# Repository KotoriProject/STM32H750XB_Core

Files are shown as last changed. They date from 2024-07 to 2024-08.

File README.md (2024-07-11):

# STM32 H750XBH6 核心板设计规划
## 设计理念
从STM32的F0、F1系列一路至今，到目前最为复杂的H750IBK6开发板、核心板的设计，逐渐认识到了单片机系统的设计思路。

在使用低性能单片机的情况下，通常最小系统的PCB layout只需要普通的两层即可。因此，在这种情况下，应当尽量采用**一体化设计**，既可以节省PCB成本，又无需考虑多个PCB之间的耦合设计。

但如果使用的是像H7这一类的**高性能芯片**，并且，这些芯片因为其封装、外部扩展ram等等，会导致最小系统的复杂度急剧提升，PCB layout通常都需要**4层甚至以上的设计**，此时，如果还像低性能单片机一样一体化设计，将核心系统和外围系统设计到一个PCB上，不仅会无故增加成本，并且每一个不同的项目需求的外围电路不尽相同，若更改外围电路则需要连同核心系统一起更改，将会**花费大量时间在重复设计核心系统上**。

因此，采用核心板+底板的设计方式应运而生。通过将核心系统单独设计成一块固定的PCB，并通过引出**具有通用性的接口**，可以使得核心系统**随意**搭配不同的底板（外围电路）。
## 设计目标
1. 通过设计该核心板和对应配套的底板，在实践中学习到相应的知识。
2. 设计出一款可以使用核心芯片所具有的广泛的外设接口、并核心自身又有搭载必要的**内存拓展空间**。
3. 利用设计出的核心板和底板，实现各种个人构想的项目。

## 硬件设计
### Power
参考ST官方给出的H7电源设计，STM32H750XBH6共有以下供电域：

1. dw
2. 123
3. 321
4. 313421414
5. 
123321414
### External Memory
### GPIO AFIO
### Debug Port
### Physical Port

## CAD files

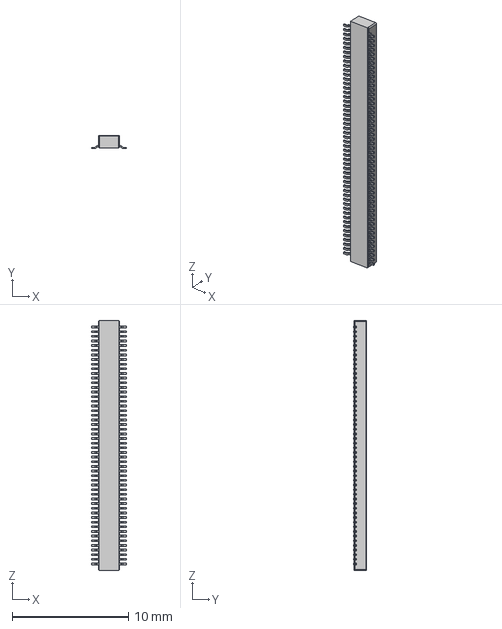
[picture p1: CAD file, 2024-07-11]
PCB/kicad_project/HRS/DF40C-100DP-0.4V_51_.step
2.97 x 1.14 x 21.5 mm

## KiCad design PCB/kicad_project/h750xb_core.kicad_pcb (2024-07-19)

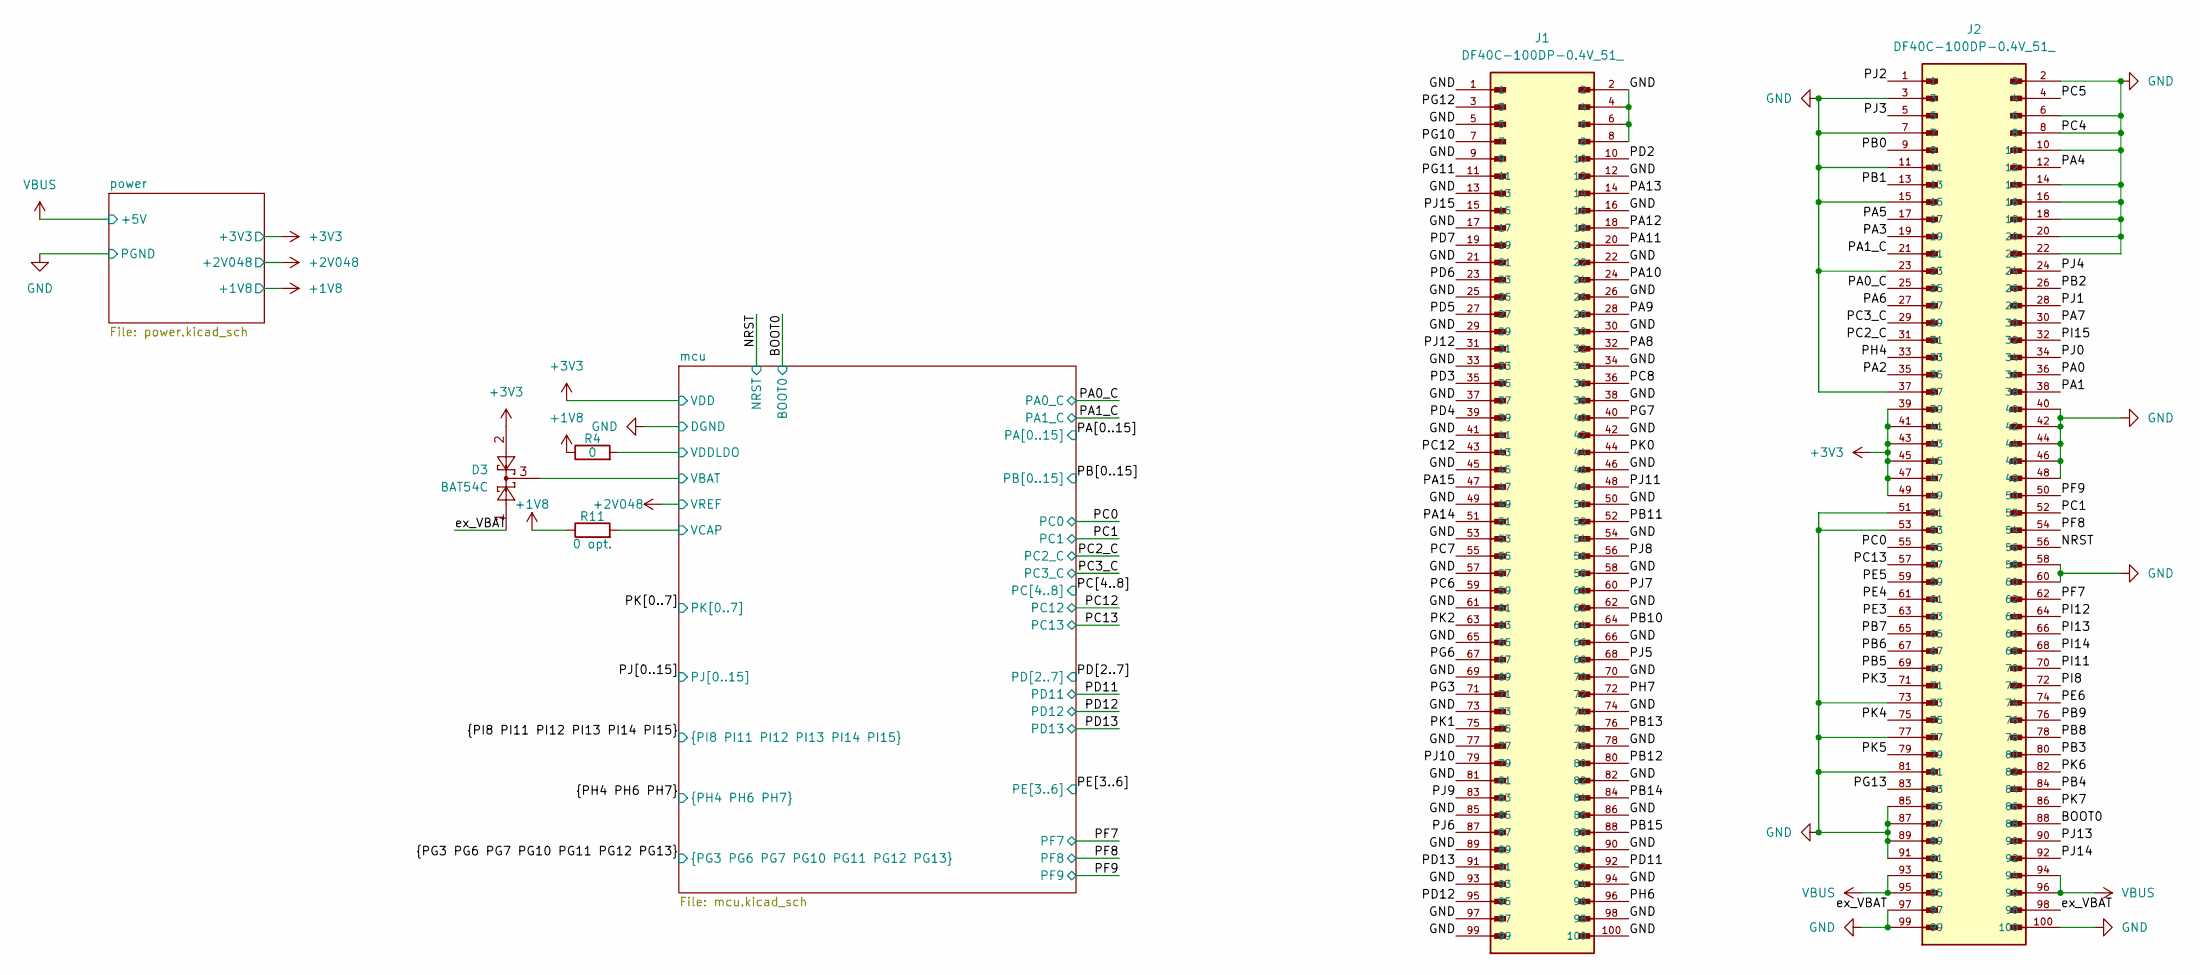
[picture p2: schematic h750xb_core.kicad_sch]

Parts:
D3: BAT54C; SOT-23
J1, J2: DF40C-100DP-0.4V_51_; HIROSE_DF40C-100DP-0.4V_51_; PARTREV 8
R4: 0; R_0603_1608Metric
R11: 0 opt.; R_0603_1608Metric

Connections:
+1V8: R4.1, R11.1; also elsewhere on the board
+3V3: D3.2, J2.39, J2.41, J2.43, J2.45, J2.47, J2.49; also elsewhere on the board
/BOOT0: J2.88; also elsewhere on the board
/NRST: J2.56; also elsewhere on the board
/PA0: J2.36; also elsewhere on the board
/PA0_C: J2.25; also elsewhere on the board
/PA1: J2.38; also elsewhere on the board
/PA1_C: J2.21; also elsewhere on the board
/PA2: J2.35; also elsewhere on the board
/PA3: J2.19; also elsewhere on the board
/PA4: J2.12; also elsewhere on the board
/PA5: J2.17; also elsewhere on the board
/PA6: J2.27; also elsewhere on the board
/PA7: J2.30; also elsewhere on the board
/PA8: J1.32; also elsewhere on the board
/PA9: J1.28; also elsewhere on the board
/PA10: J1.24; also elsewhere on the board
/PA11: J1.20; also elsewhere on the board
/PA12: J1.18; also elsewhere on the board
/PA13: J1.14; also elsewhere on the board
/PA14: J1.51; also elsewhere on the board
/PA15: J1.47; also elsewhere on the board
/PB0: J2.9; also elsewhere on the board
/PB1: J2.13; also elsewhere on the board
/PB2: J2.26; also elsewhere on the board
/PB3: J2.80; also elsewhere on the board
/PB4: J2.84; also elsewhere on the board
/PB5: J2.69; also elsewhere on the board
/PB6: J2.67; also elsewhere on the board
/PB7: J2.65; also elsewhere on the board
/PB8: J2.78; also elsewhere on the board
/PB9: J2.76; also elsewhere on the board
/PB10: J1.64; also elsewhere on the board
/PB11: J1.52; also elsewhere on the board
/PB12: J1.80; also elsewhere on the board
/PB13: J1.76; also elsewhere on the board
/PB14: J1.84; also elsewhere on the board
/PB15: J1.88; also elsewhere on the board
/PC0: J2.55; also elsewhere on the board
/PC1: J2.52; also elsewhere on the board
/PC2_C: J2.31; also elsewhere on the board
/PC3_C: J2.29; also elsewhere on the board
/PC5: J2.4; also elsewhere on the board
/PC6: J1.59; also elsewhere on the board
/PC7: J1.55; also elsewhere on the board
/PC8: J1.36; also elsewhere on the board
/PC12: J1.43; also elsewhere on the board
/PC13: J2.57; also elsewhere on the board
/PD2: J1.10; also elsewhere on the board
/PD3: J1.35; also elsewhere on the board
/PD4: J1.39; also elsewhere on the board
/PD5: J1.27; also elsewhere on the board
/PD6: J1.23; also elsewhere on the board
/PD7: J1.19; also elsewhere on the board
/PD11: J1.92; also elsewhere on the board
/PD12: J1.95; also elsewhere on the board
/PD13: J1.91; also elsewhere on the board
/PE3: J2.63; also elsewhere on the board
/PE4: J2.61; also elsewhere on the board
/PE5: J2.59; also elsewhere on the board
/PE6: J2.74; also elsewhere on the board
/PF7: J2.62; also elsewhere on the board
/PF8: J2.54; also elsewhere on the board
/PF9: J2.50; also elsewhere on the board
/PG3: J1.71; also elsewhere on the board
/PG6: J1.67; also elsewhere on the board
/PG7: J1.40; also elsewhere on the board
/PG10: J1.7; also elsewhere on the board
/PG11: J1.11; also elsewhere on the board
/PG12: J1.3; also elsewhere on the board
/PG13: J2.83; also elsewhere on the board
/PH4: J2.33; also elsewhere on the board
/PH6: J1.96; also elsewhere on the board
/PH7: J1.72; also elsewhere on the board
/PI8: J2.72; also elsewhere on the board
/PI11: J2.70; also elsewhere on the board
/PI12: J2.64; also elsewhere on the board
/PI13: J2.66; also elsewhere on the board
/PI14: J2.68; also elsewhere on the board
/PI15: J2.32; also elsewhere on the board
/PJ0: J2.34; also elsewhere on the board
/PJ1: J2.28; also elsewhere on the board
/PJ2: J2.1; also elsewhere on the board
/PJ3: J2.5; also elsewhere on the board
/PJ4: J2.24; also elsewhere on the board
/PJ5: J1.68; also elsewhere on the board
/PJ6: J1.87; also elsewhere on the board
/PJ7: J1.60; also elsewhere on the board
/PJ8: J1.56; also elsewhere on the board
/PJ9: J1.83; also elsewhere on the board
/PJ10: J1.79; also elsewhere on the board
/PJ11: J1.48; also elsewhere on the board
/PJ12: J1.31; also elsewhere on the board
/PJ13: J2.90; also elsewhere on the board
/PJ14: J2.92; also elsewhere on the board
/PJ15: J1.15; also elsewhere on the board
/PK0: J1.44; also elsewhere on the board
/PK1: J1.75; also elsewhere on the board
/PK2: J1.63; also elsewhere on the board
/PK3: J2.71; also elsewhere on the board
/PK4: J2.75; also elsewhere on the board
/PK5: J2.79; also elsewhere on the board
/PK6: J2.82; also elsewhere on the board
/PK7: J2.86; also elsewhere on the board
/mcu/VBAT: D3.3; also elsewhere on the board
/mcu/VCAP: R11.2; also elsewhere on the board
/mcu/VDDLDO: R4.2; also elsewhere on the board
GND: D3.1, J1.1, J1.2, J1.4, J1.5, J1.6, J1.8, J1.9, J1.12, J1.13, J1.16, J1.17, J1.21, J1.22, J1.25, J1.26, J1.29, J1.30, J1.33, J1.34, J1.37, J1.38, J1.41, J1.42, J1.45, J1.46, J1.49, J1.50, J1.53, J1.54, J1.57, J1.58, J1.61, J1.62, J1.65, J1.66, J1.69, J1.70, J1.73, J1.74, J1.77, J1.78, J1.81, J1.82, J1.85, J1.86, J1.89, J1.90, J1.93, J1.94, J1.97, J1.98, J1.99, J1.100, J2.2, J2.3, J2.6, J2.7, J2.8, J2.10, J2.11, J2.14, J2.15, J2.16, J2.18, J2.20, J2.22, J2.23, J2.37, J2.40, J2.42, J2.44, J2.46, J2.48, J2.51, J2.53, J2.58, J2.60, J2.73, J2.77, J2.81, J2.85, J2.87, J2.89, J2.91, J2.97, J2.98, J2.99, J2.100; also elsewhere on the board
VBUS: J2.93, J2.94, J2.95, J2.96; also elsewhere on the board

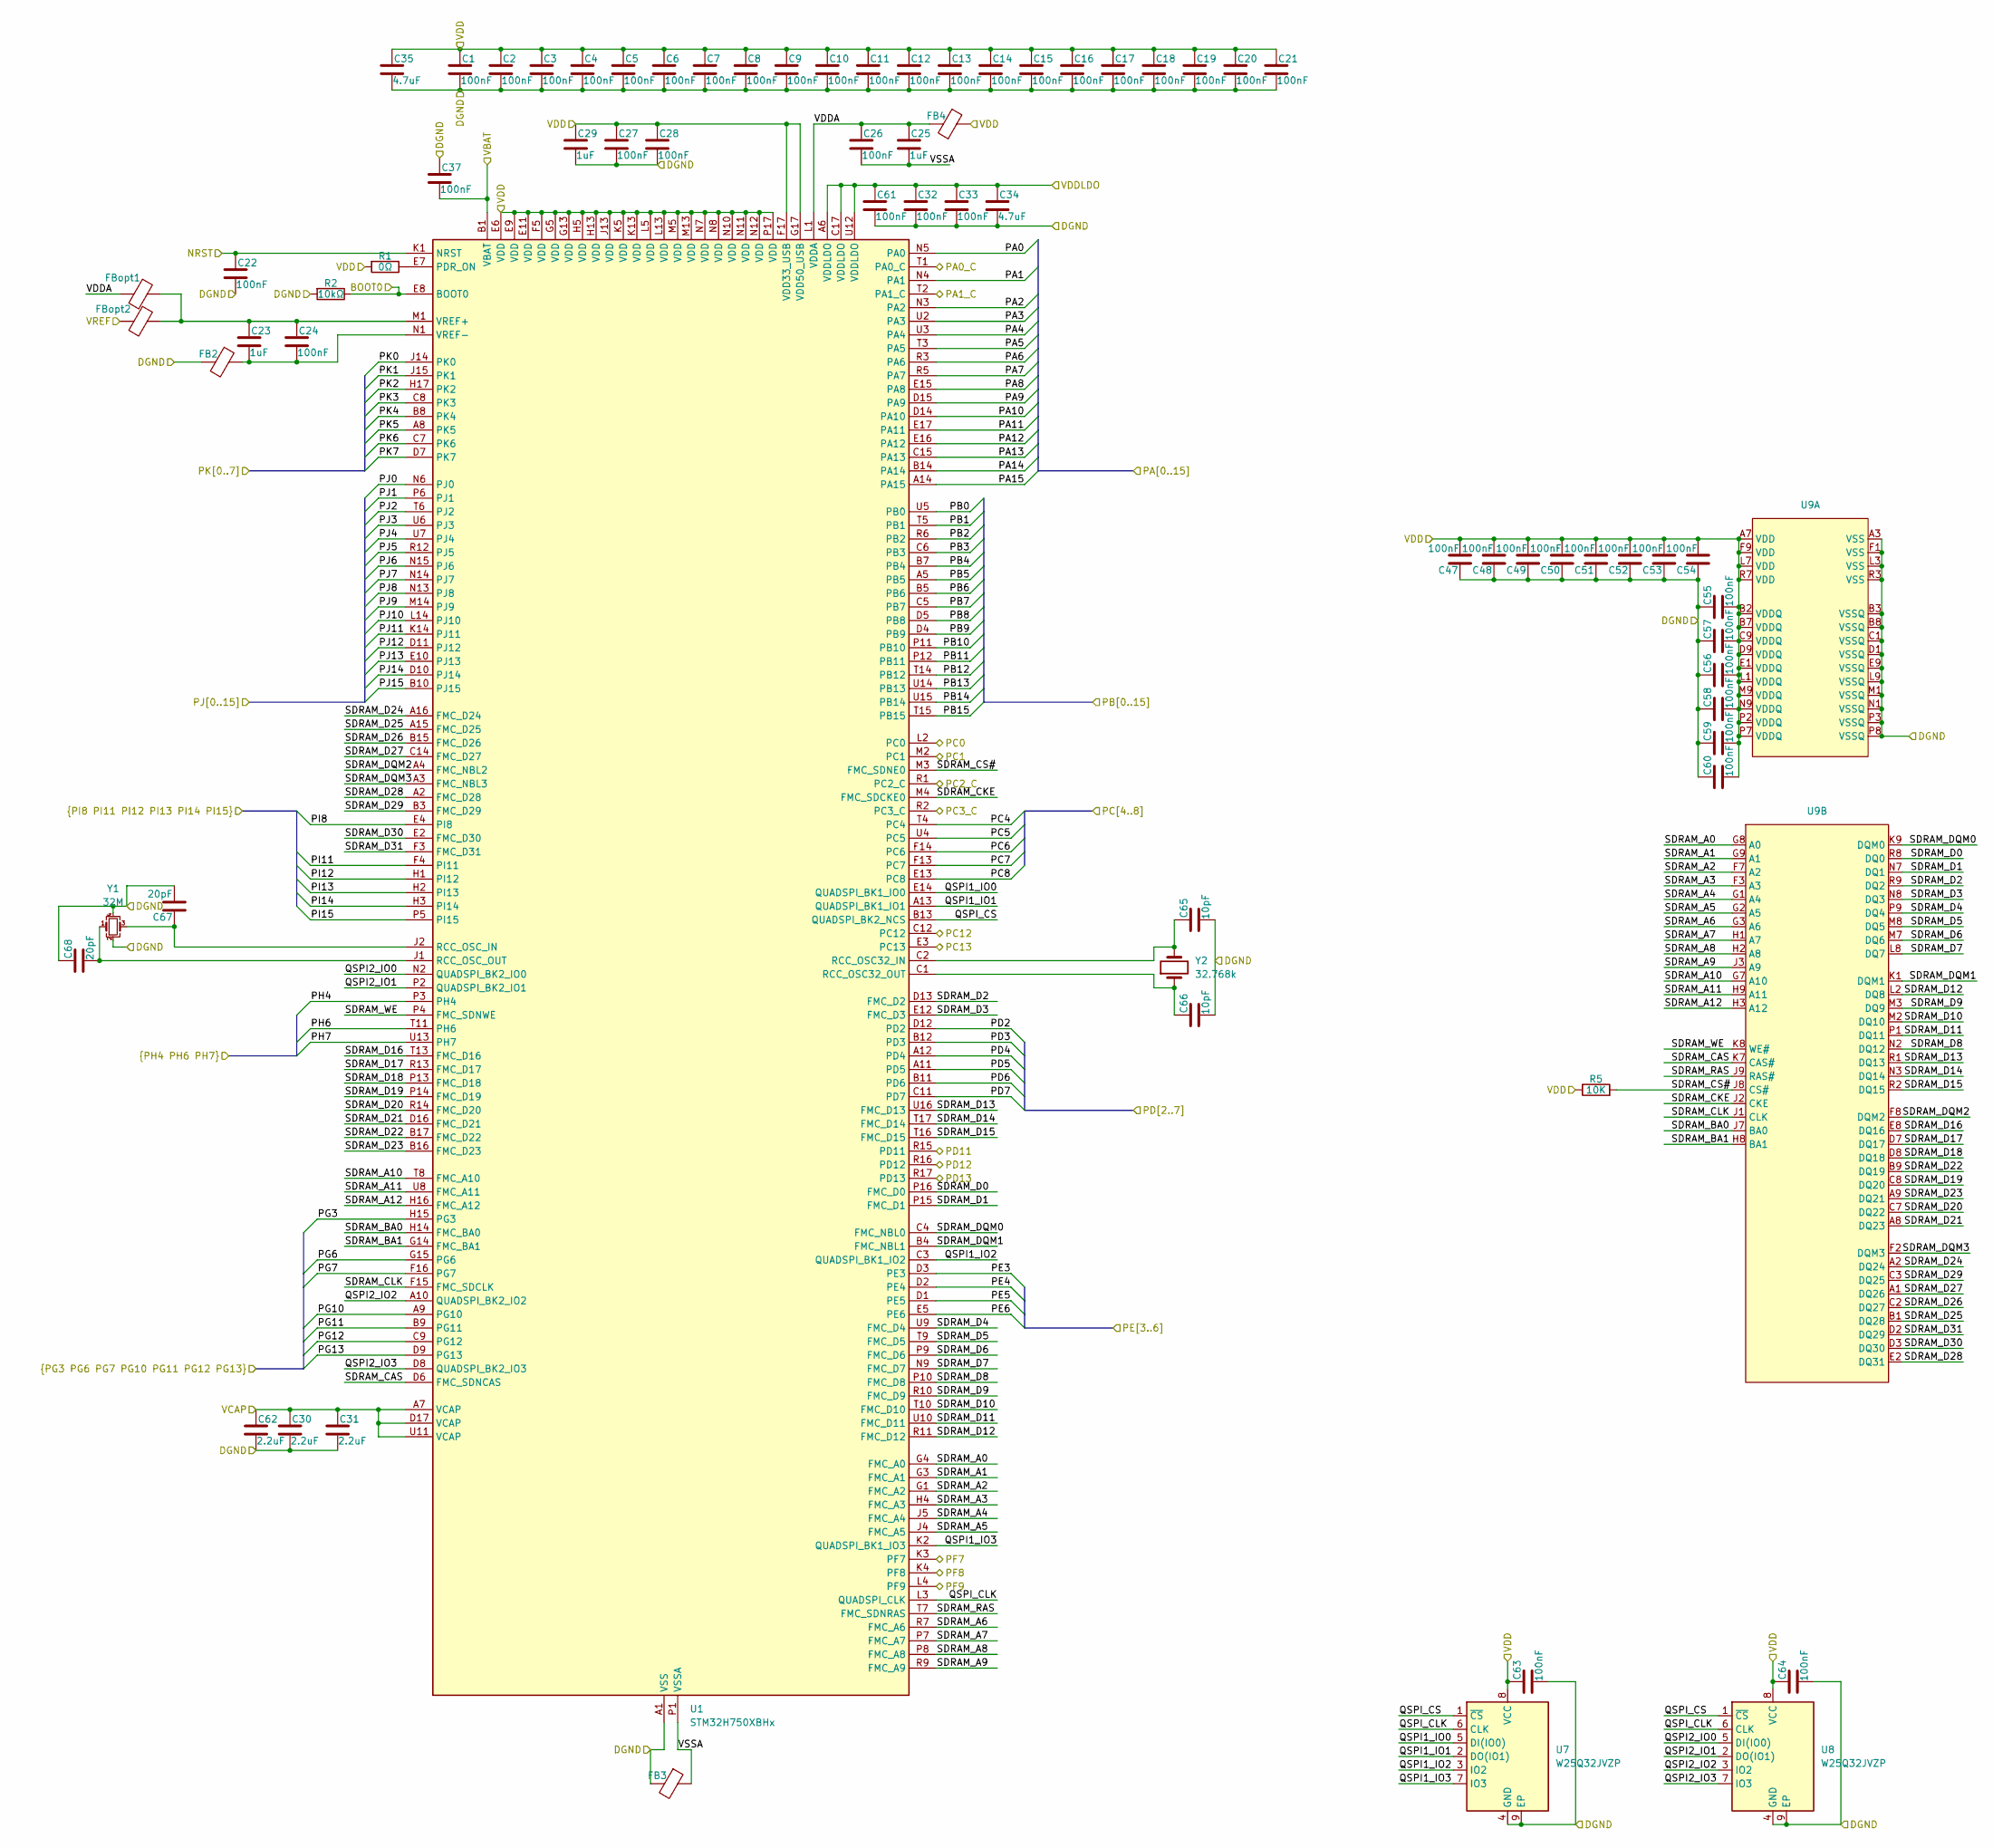
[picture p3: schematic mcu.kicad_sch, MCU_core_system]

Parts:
C1, C3, C4, C5, C6, C7, C8, C9, C10, C11, C12, C13, C14, C15, C17, C18, C19, C20, C21: 100nF; C_0201_0603Metric_Pad0.64x0.40mm_HandSolder
C2, C16, C22, C24, C26, C27, C28, C32, C33, C37, C47, C48, C49, C50, C51, C52, C53, C54, C55, C56, C57, C58, C59, C60, C61, C63, C64: 100nF; C_0402_1005Metric
C23, C25, C29: 1uF; C_0402_1005Metric
C30, C31, C62: 2.2uF; C_0402_1005Metric
C34, C35: 4.7uF; C_0402_1005Metric
C65, C66: 10pF; C_0402_1005Metric
C67, C68: 20pF; C_0402_1005Metric
FB2, FB3, FB4: 120Ω; L_0603_1608Metric; LCSC C14709
FBopt1, FBopt2: 120Ω; L_0603_1608Metric; LCSC C14709
R1: 0Ω; R_0402_1005Metric
R2: 10kΩ; R_0402_1005Metric
R5: 10K; R_0402_1005Metric
U1: STM32H750XBHx; TFBGA-265_14x14mm_Layout17x17_P0.8mm
U7, U8: W25Q32JVZP; WSON-8-1EP_6x5mm_P1.27mm_EP3.4x4.3mm
U9: BGA-90_8.0x13.0mm_Layout2x3x15_P0.8mm; Manufacturer Part IS42S32160F-7BLI; LCSC Part Name IS42S32160F-7BLI
Y1: 32M; Crystal_SMD_2016-4Pin_2.0x1.6mm; LCSC C2965582
Y2: 32.768k; Crystal_SMD_3215-2Pin_3.2x1.5mm; LCSC C48615

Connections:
+2V048: FBopt2.2; also elsewhere on the board
+3V3: C1.1, C2.1, C3.1, C4.1, C5.1, C6.1, C7.1, C8.1, C9.1, C10.1, C11.1, C12.1, C13.1, C14.1, C15.1, C16.1, C17.1, C18.1, C19.1, C20.1, C21.1, C27.1, C28.1, C29.1, C35.1, C47.2, C48.2, C49.2, C50.2, C51.2, C52.2, C53.2, C54.2, C55.2, C56.2, C57.2, C58.2, C59.2, C60.2, C63.1, C64.1, FB4.1, R1.2, R5.1, U1.E6 (VDD), U1.E9 (VDD), U1.E11 (VDD), U1.F5 (VDD), U1.F17 (VDD33_USB), U1.G5 (VDD), U1.G13 (VDD), U1.G17 (VDD50_USB), U1.H5 (VDD), U1.H13 (VDD), U1.J13 (VDD), U1.K5 (VDD), U1.K13 (VDD), U1.L5 (VDD), U1.L13 (VDD), U1.M5 (VDD), U1.M13 (VDD), U1.N7 (VDD), U1.N8 (VDD), U1.N10 (VDD), U1.N11 (VDD), U1.N12 (VDD), U1.P17 (VDD), U7.8 (VCC), U8.8 (VCC), U9.A7 (VDD), U9.B2 (VDDQ), U9.B7 (VDDQ), U9.C9 (VDDQ), U9.D9 (VDDQ), U9.E1 (VDDQ), U9.F9 (VDD), U9.L1 (VDDQ), U9.L7 (VDD), U9.M9 (VDDQ), U9.N9 (VDDQ), U9.P2 (VDDQ), U9.P7 (VDDQ), U9.R7 (VDD); also elsewhere on the board
/BOOT0: R2.1, U1.E8 (BOOT0); also elsewhere on the board
/NRST: C22.1, U1.K1 (NRST); also elsewhere on the board
/PA0: U1.N5 (PA0); also elsewhere on the board
/PA0_C: U1.T1 (PA0_C); also elsewhere on the board
/PA1: U1.N4 (PA1); also elsewhere on the board
/PA1_C: U1.T2 (PA1_C); also elsewhere on the board
/PA2: U1.N3 (PA2); also elsewhere on the board
/PA3: U1.U2 (PA3); also elsewhere on the board
/PA4: U1.U3 (PA4); also elsewhere on the board
/PA5: U1.T3 (PA5); also elsewhere on the board
/PA6: U1.R3 (PA6); also elsewhere on the board
/PA7: U1.R5 (PA7); also elsewhere on the board
/PA8: U1.E15 (PA8); also elsewhere on the board
/PA9: U1.D15 (PA9); also elsewhere on the board
/PA10: U1.D14 (PA10); also elsewhere on the board
/PA11: U1.E17 (PA11); also elsewhere on the board
/PA12: U1.E16 (PA12); also elsewhere on the board
/PA13: U1.C15 (PA13); also elsewhere on the board
/PA14: U1.B14 (PA14); also elsewhere on the board
/PA15: U1.A14 (PA15); also elsewhere on the board
/PB0: U1.U5 (PB0); also elsewhere on the board
/PB1: U1.T5 (PB1); also elsewhere on the board
/PB2: U1.R6 (PB2); also elsewhere on the board
/PB3: U1.C6 (PB3); also elsewhere on the board
/PB4: U1.B7 (PB4); also elsewhere on the board
/PB5: U1.A5 (PB5); also elsewhere on the board
/PB6: U1.B5 (PB6); also elsewhere on the board
/PB7: U1.C5 (PB7); also elsewhere on the board
/PB8: U1.D5 (PB8); also elsewhere on the board
/PB9: U1.D4 (PB9); also elsewhere on the board
/PB10: U1.P11 (PB10); also elsewhere on the board
/PB11: U1.P12 (PB11); also elsewhere on the board
/PB12: U1.T14 (PB12); also elsewhere on the board
/PB13: U1.U14 (PB13); also elsewhere on the board
/PB14: U1.U15 (PB14); also elsewhere on the board
/PB15: U1.T15 (PB15); also elsewhere on the board
/PC0: U1.L2 (PC0); also elsewhere on the board
/PC1: U1.M2 (PC1); also elsewhere on the board
/PC2_C: U1.R1 (PC2_C); also elsewhere on the board
/PC3_C: U1.R2 (PC3_C); also elsewhere on the board
/PC5: U1.U4 (PC5); also elsewhere on the board
/PC6: U1.F14 (PC6); also elsewhere on the board
/PC7: U1.F13 (PC7); also elsewhere on the board
/PC8: U1.E13 (PC8); also elsewhere on the board
/PC12: U1.C12; also elsewhere on the board
/PC13: U1.E3 (PC13); also elsewhere on the board
/PD2: U1.D12 (PD2); also elsewhere on the board
/PD3: U1.B12 (PD3); also elsewhere on the board
/PD4: U1.A12 (PD4); also elsewhere on the board
/PD5: U1.A11 (PD5); also elsewhere on the board
/PD6: U1.B11 (PD6); also elsewhere on the board
/PD7: U1.C11 (PD7); also elsewhere on the board
/PD11: U1.R15 (PD11); also elsewhere on the board
/PD12: U1.R16 (PD12); also elsewhere on the board
/PD13: U1.R17 (PD13); also elsewhere on the board
/PE3: U1.D3 (PE3); also elsewhere on the board
/PE4: U1.D2 (PE4); also elsewhere on the board
/PE5: U1.D1 (PE5); also elsewhere on the board
/PE6: U1.E5 (PE6); also elsewhere on the board
/PF7: U1.K3 (PF7); also elsewhere on the board
/PF8: U1.K4 (PF8); also elsewhere on the board
/PF9: U1.L4 (PF9); also elsewhere on the board
/PG3: U1.H15 (PG3); also elsewhere on the board
/PG6: U1.G15 (PG6); also elsewhere on the board
/PG7: U1.F16 (PG7); also elsewhere on the board
/PG10: U1.A9 (PG10); also elsewhere on the board
/PG11: U1.B9 (PG11); also elsewhere on the board
/PG12: U1.C9 (PG12); also elsewhere on the board
/PG13: U1.D9 (PG13); also elsewhere on the board
/PH4: U1.P3 (PH4); also elsewhere on the board
/PH6: U1.T11 (PH6); also elsewhere on the board
/PH7: U1.U13 (PH7); also elsewhere on the board
/PI8: U1.E4 (PI8); also elsewhere on the board
/PI11: U1.F4 (PI11); also elsewhere on the board
/PI12: U1.H1 (PI12); also elsewhere on the board
/PI13: U1.H2 (PI13); also elsewhere on the board
/PI14: U1.H3 (PI14); also elsewhere on the board
/PI15: U1.P5 (PI15); also elsewhere on the board
/PJ0: U1.N6 (PJ0); also elsewhere on the board
/PJ1: U1.P6 (PJ1); also elsewhere on the board
/PJ2: U1.T6 (PJ2); also elsewhere on the board
/PJ3: U1.U6 (PJ3); also elsewhere on the board
/PJ4: U1.U7 (PJ4); also elsewhere on the board
/PJ5: U1.R12 (PJ5); also elsewhere on the board
/PJ6: U1.N15 (PJ6); also elsewhere on the board
/PJ7: U1.N14 (PJ7); also elsewhere on the board
/PJ8: U1.N13 (PJ8); also elsewhere on the board
/PJ9: U1.M14 (PJ9); also elsewhere on the board
/PJ10: U1.L14 (PJ10); also elsewhere on the board
/PJ11: U1.K14 (PJ11); also elsewhere on the board
/PJ12: U1.D11 (PJ12); also elsewhere on the board
/PJ13: U1.E10 (PJ13); also elsewhere on the board
/PJ14: U1.D10 (PJ14); also elsewhere on the board
/PJ15: U1.B10 (PJ15); also elsewhere on the board
/PK0: U1.J14 (PK0); also elsewhere on the board
/PK1: U1.J15 (PK1); also elsewhere on the board
/PK2: U1.H17 (PK2); also elsewhere on the board
/PK3: U1.C8 (PK3); also elsewhere on the board
/PK4: U1.B8 (PK4); also elsewhere on the board
/PK5: U1.A8 (PK5); also elsewhere on the board
/PK6: U1.C7 (PK6); also elsewhere on the board
/PK7: U1.D7 (PK7); also elsewhere on the board
/mcu/QSPI1_IO0: U1.E14 (QUADSPI_BK1_IO0), U7.5 (DI(IO0))
/mcu/QSPI1_IO1: U1.A13 (QUADSPI_BK1_IO1), U7.2 (DO(IO1))
/mcu/QSPI1_IO2: U1.C3 (QUADSPI_BK1_IO2), U7.3 (IO2)
/mcu/QSPI1_IO3: U1.K2 (QUADSPI_BK1_IO3), U7.7 (IO3)
/mcu/QSPI2_IO0: U1.N2 (QUADSPI_BK2_IO0), U8.5 (DI(IO0))
/mcu/QSPI2_IO1: U1.P2 (QUADSPI_BK2_IO1), U8.2 (DO(IO1))
/mcu/QSPI2_IO2: U1.A10 (QUADSPI_BK2_IO2), U8.3 (IO2)
/mcu/QSPI2_IO3: U1.D8 (QUADSPI_BK2_IO3), U8.7 (IO3)
/mcu/QSPI_CLK: U1.L3 (QUADSPI_CLK), U7.6 (CLK), U8.6 (CLK)
/mcu/QSPI_CS: U1.B13 (QUADSPI_BK2_NCS), U7.1 (~CS), U8.1 (~CS)
/mcu/SDRAM_A0: U1.G4 (FMC_A0), U9.G8 (A0)
/mcu/SDRAM_A1: U1.G3 (FMC_A1), U9.G9 (A1)
/mcu/SDRAM_A2: U1.G1 (FMC_A2), U9.F7 (A2)
/mcu/SDRAM_A3: U1.H4 (FMC_A3), U9.F3 (A3)
/mcu/SDRAM_A4: U1.J5 (FMC_A4), U9.G1 (A4)
/mcu/SDRAM_A5: U1.J4 (FMC_A5), U9.G2 (A5)
/mcu/SDRAM_A6: U1.R7 (FMC_A6), U9.G3 (A6)
/mcu/SDRAM_A7: U1.P7 (FMC_A7), U9.H1 (A7)
/mcu/SDRAM_A8: U1.P8 (FMC_A8), U9.H2 (A8)
/mcu/SDRAM_A9: U1.R9 (FMC_A9), U9.J3 (A9)
/mcu/SDRAM_A10: U1.T8 (FMC_A10), U9.G7 (A10)
/mcu/SDRAM_A11: U1.U8 (FMC_A11), U9.H9 (A11)
/mcu/SDRAM_A12: U1.H16 (FMC_A12), U9.H3 (A12)
/mcu/SDRAM_BA0: U1.H14 (FMC_BA0), U9.J7 (BA0)
/mcu/SDRAM_BA1: U1.G14 (FMC_BA1), U9.H8 (BA1)
/mcu/SDRAM_CAS: U1.D6 (FMC_SDNCAS), U9.K7 (CAS#)
/mcu/SDRAM_CKE: U1.M4 (FMC_SDCKE0), U9.J2 (CKE)
/mcu/SDRAM_CLK: U1.F15 (FMC_SDCLK), U9.J1 (CLK)
/mcu/SDRAM_CS#: R5.2, U1.M3 (FMC_SDNE0), U9.J8 (CS#)
/mcu/SDRAM_D0: U1.P16 (FMC_D0), U9.R8 (DQ0)
/mcu/SDRAM_D1: U1.P15 (FMC_D1), U9.N7 (DQ1)
/mcu/SDRAM_D2: U1.D13 (FMC_D2), U9.R9 (DQ2)
/mcu/SDRAM_D3: U1.E12 (FMC_D3), U9.N8 (DQ3)
/mcu/SDRAM_D4: U1.U9 (FMC_D4), U9.P9 (DQ4)
/mcu/SDRAM_D5: U1.T9 (FMC_D5), U9.M8 (DQ5)
/mcu/SDRAM_D6: U1.P9 (FMC_D6), U9.M7 (DQ6)
/mcu/SDRAM_D7: U1.N9 (FMC_D7), U9.L8 (DQ7)
/mcu/SDRAM_D8: U1.P10 (FMC_D8), U9.N2 (DQ12)
/mcu/SDRAM_D9: U1.R10 (FMC_D9), U9.M3 (DQ9)
/mcu/SDRAM_D10: U1.T10 (FMC_D10), U9.M2 (DQ10)
/mcu/SDRAM_D11: U1.U10 (FMC_D11), U9.P1 (DQ11)
/mcu/SDRAM_D12: U1.R11 (FMC_D12), U9.L2 (DQ8)
/mcu/SDRAM_D13: U1.U16 (FMC_D13), U9.R1 (DQ13)
/mcu/SDRAM_D14: U1.T17 (FMC_D14), U9.N3 (DQ14)
/mcu/SDRAM_D15: U1.T16 (FMC_D15), U9.R2 (DQ15)
/mcu/SDRAM_D16: U1.T13 (FMC_D16), U9.E8 (DQ16)
/mcu/SDRAM_D17: U1.R13 (FMC_D17), U9.D7 (DQ17)
/mcu/SDRAM_D18: U1.P13 (FMC_D18), U9.D8 (DQ18)
/mcu/SDRAM_D19: U1.P14 (FMC_D19), U9.C8 (DQ20)
/mcu/SDRAM_D20: U1.R14 (FMC_D20), U9.C7 (DQ22)
/mcu/SDRAM_D21: U1.D16 (FMC_D21), U9.A8 (DQ23)
/mcu/SDRAM_D22: U1.B17 (FMC_D22), U9.B9 (DQ19)
/mcu/SDRAM_D23: U1.B16 (FMC_D23), U9.A9 (DQ21)
/mcu/SDRAM_D24: U1.A16 (FMC_D24), U9.A2 (DQ24)
/mcu/SDRAM_D25: U1.A15 (FMC_D25), U9.B1 (DQ28)
/mcu/SDRAM_D26: U1.B15 (FMC_D26), U9.C2 (DQ27)
/mcu/SDRAM_D27: U1.C14 (FMC_D27), U9.A1 (DQ26)
/mcu/SDRAM_D28: U1.A2 (FMC_D28), U9.E2 (DQ31)
/mcu/SDRAM_D29: U1.B3 (FMC_D29), U9.C3 (DQ25)
/mcu/SDRAM_D30: U1.E2 (FMC_D30), U9.D3 (DQ30)
/mcu/SDRAM_D31: U1.F3 (FMC_D31), U9.D2 (DQ29)
/mcu/SDRAM_DQM0: U1.C4 (FMC_NBL0), U9.K9 (DQM0)
/mcu/SDRAM_DQM1: U1.B4 (FMC_NBL1), U9.K1 (DQM1)
/mcu/SDRAM_DQM2: U1.A4 (FMC_NBL2), U9.F8 (DQM2)
/mcu/SDRAM_DQM3: U1.A3 (FMC_NBL3), U9.F2 (DQM3)
/mcu/SDRAM_RAS: U1.T7 (FMC_SDNRAS), U9.J9 (RAS#)
/mcu/SDRAM_WE: U1.P4 (FMC_SDNWE), U9.K8 (WE#)
/mcu/VBAT: C37.2, U1.B1 (VBAT); also elsewhere on the board
/mcu/VCAP: C30.1, C31.1, C62.1, U1.A7 (VCAP), U1.D17 (VCAP), U1.U11 (VCAP); also elsewhere on the board
/mcu/VDDA: C25.1, C26.1, FB4.2, FBopt1.2, U1.L1 (VDDA)
/mcu/VDDLDO: C32.1, C33.1, C34.1, C61.1, U1.A6 (VDDLDO), U1.C17 (VDDLDO), U1.U12 (VDDLDO); also elsewhere on the board
/mcu/VSSA: C25.2, C26.2, FB3.1, U1.P1 (VSSA)
GND: C1.2, C2.2, C3.2, C4.2, C5.2, C6.2, C7.2, C8.2, C9.2, C10.2, C11.2, C12.2, C13.2, C14.2, C15.2, C16.2, C17.2, C18.2, C19.2, C20.2, C21.2, C22.2, C27.2, C28.2, C29.2, C30.2, C31.2, C32.2, C33.2, C34.2, C35.2, C37.1, C47.1, C48.1, C49.1, C50.1, C51.1, C52.1, C53.1, C54.1, C55.1, C56.1, C57.1, C58.1, C59.1, C60.1, C61.2, C62.2, C63.2, C64.2, C65.2, C66.2, C67.2, C68.1, FB2.2, FB3.2, R2.2, U1.A1 (VSS), U1.A17 (VSS), U1.B2 (VSS), U1.B6 (VSS), U1.C10 (VSS), U1.C13 (VSS), U1.C16 (VSS), U1.F1 (VSS), U1.F2 (VSS), U1.G2 (VSS), U1.G7 (VSS), U1.G8 (VSS), U1.G9 (VSS), U1.G10 (VSS), U1.G11 (VSS), U1.G16 (VSS), U1.H7 (VSS), U1.H8 (VSS), U1.H9 (VSS), U1.H10 (VSS), U1.H11 (VSS), U1.J3 (VSS), U1.J7 (VSS), U1.J8 (VSS), U1.J9 (VSS), U1.J10 (VSS), U1.J11 (VSS), U1.J16 (VSS), U1.J17 (VSS), U1.K7 (VSS), U1.K8 (VSS), U1.K9 (VSS), U1.K10 (VSS), U1.K11 (VSS), U1.K15 (VSS), U1.L7 (VSS), U1.L8 (VSS), U1.L9 (VSS), U1.L10 (VSS), U1.L11 (VSS), U1.L15 (VSS), U1.M15 (VSS), U1.N16 (VSS), U1.R4 (VSS), U1.R8 (VSS), U1.T4 (PC4), U1.T12 (VSS), U1.U1 (VSS), U1.U17 (VSS), U7.4 (GND), U7.9 (EP), U8.4 (GND), U8.9 (EP), U9.A3 (VSS), U9.B3 (VSSQ), U9.B8 (VSSQ), U9.C1 (VSSQ), U9.D1 (VSSQ), U9.E9 (VSSQ), U9.F1 (VSS), U9.L3 (VSS), U9.L9 (VSSQ), U9.M1 (VSSQ), U9.N1 (VSSQ), U9.P3 (VSSQ), U9.P8 (VSSQ), U9.R3 (VSS), Y1.2, Y1.4; also elsewhere on the board
unnamed: C65.1, U1.C2 (RCC_OSC32_IN), Y2.2
unnamed: C66.1, U1.C1 (RCC_OSC32_OUT), Y2.1
unnamed: R1.1, U1.E7 (PDR_ON)
unnamed: C67.1, U1.J2 (RCC_OSC_IN), Y1.3
unnamed: C68.2, U1.J1 (RCC_OSC_OUT), Y1.1
unnamed: C23.1, C24.1, FBopt1.1, FBopt2.1, U1.M1 (VREF+)
unnamed: C23.2, C24.2, FB2.1, U1.N1 (VREF-)

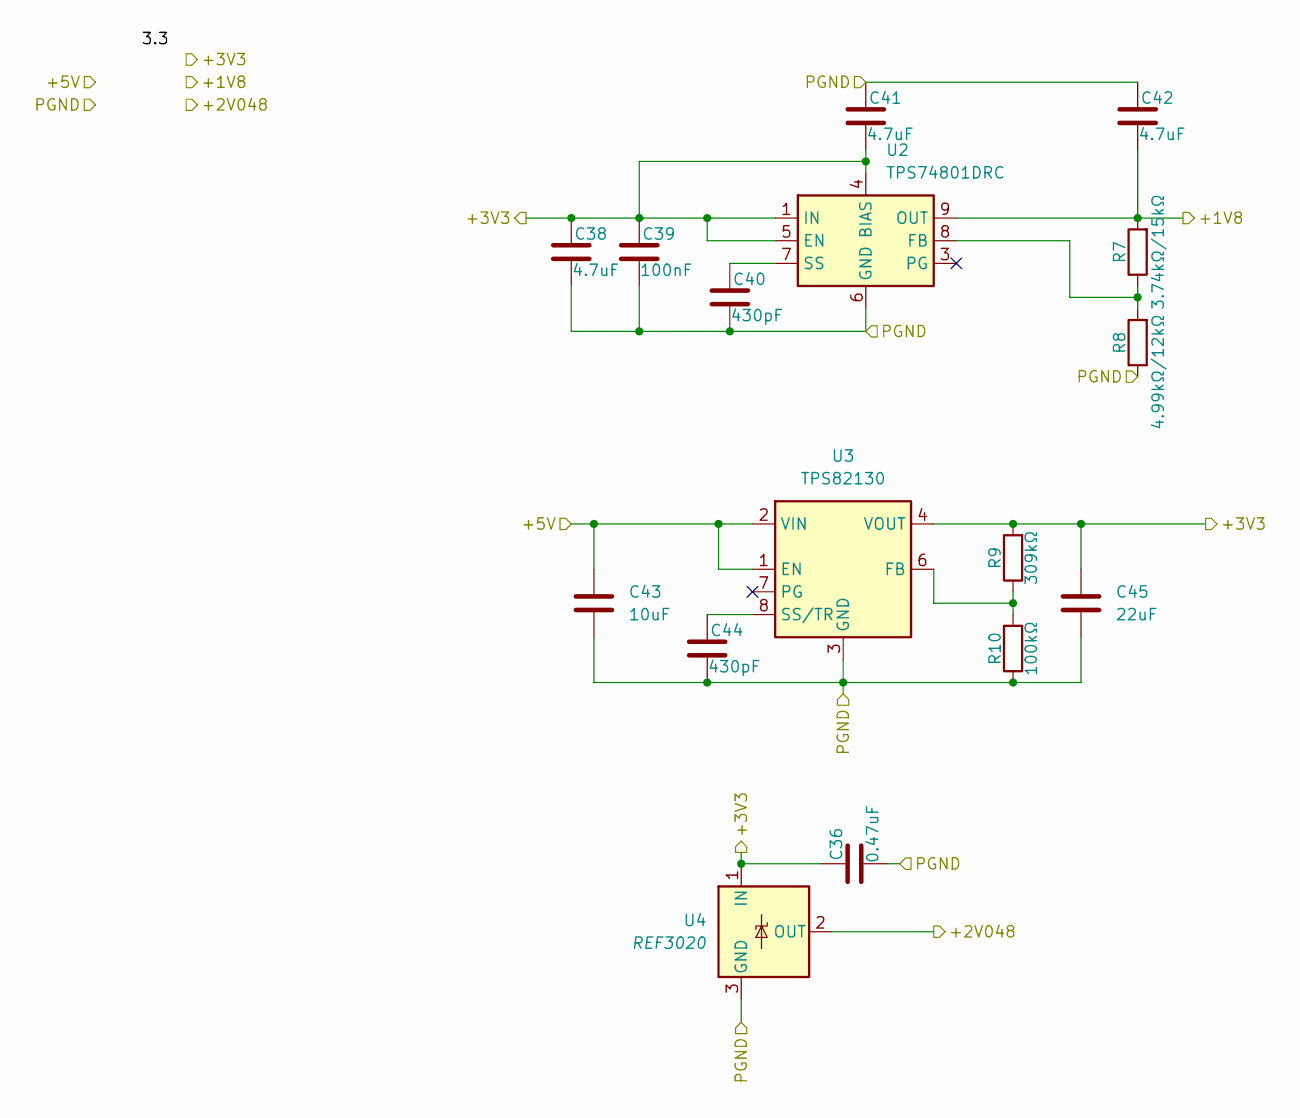
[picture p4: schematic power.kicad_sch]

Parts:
C36: 0.47uF; C_0402_1005Metric
C38, C41, C42: 4.7uF; C_0402_1005Metric
C39: 100nF; C_0402_1005Metric
C40, C44: 430pF; C_0402_1005Metric
C43: 10uF; C_0603_1608Metric
C45: 22uF; C_0603_1608Metric; LCSC C415703
R7: 3.74kΩ/15kΩ; R_0402_1005Metric
R8: 4.99kΩ/12kΩ; R_0402_1005Metric
R9: 309kΩ; R_0402_1005Metric
R10: 100kΩ; R_0402_1005Metric
U2: TPS74801DRC; VSON-10-1EP_3x3mm_P0.5mm_EP1.65x2.4mm_ThermalVias
U3: TPS82130; Texas_SIL0008D_MicroSiP-8-1EP_2.8x3mm_P0.65mm_EP1.1x1.9mm_T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
U4: REF3020; SOT-23

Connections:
+1V8: C42.2, R7.2, U2.9 (OUT), U2.10 (OUT); also elsewhere on the board
+2V048: U4.2 (OUT); also elsewhere on the board
+3V3: C36.1, C38.1, C39.1, C41.2, C45.1, R9.2, U2.1 (IN), U2.2 (IN), U2.4 (BIAS), U2.5 (EN), U3.4 (VOUT), U3.5 (VOUT), U4.1 (IN); also elsewhere on the board
GND: C36.2, C38.2, C39.2, C40.2, C41.1, C42.1, C43.2, C44.2, C45.2, R8.1, R10.1, U2.6 (GND), U2.11 (GND), U3.3 (GND), U3.9 (GND), U4.3 (GND); also elsewhere on the board
unnamed: R7.1, R8.2, U2.8 (FB)
unnamed: C40.1, U2.7 (SS)
unnamed: R9.1, R10.2, U3.6 (FB)
unnamed: C44.1, U3.8 (SS/TR)
VBUS: C43.1, U3.1 (EN), U3.2 (VIN); also elsewhere on the board

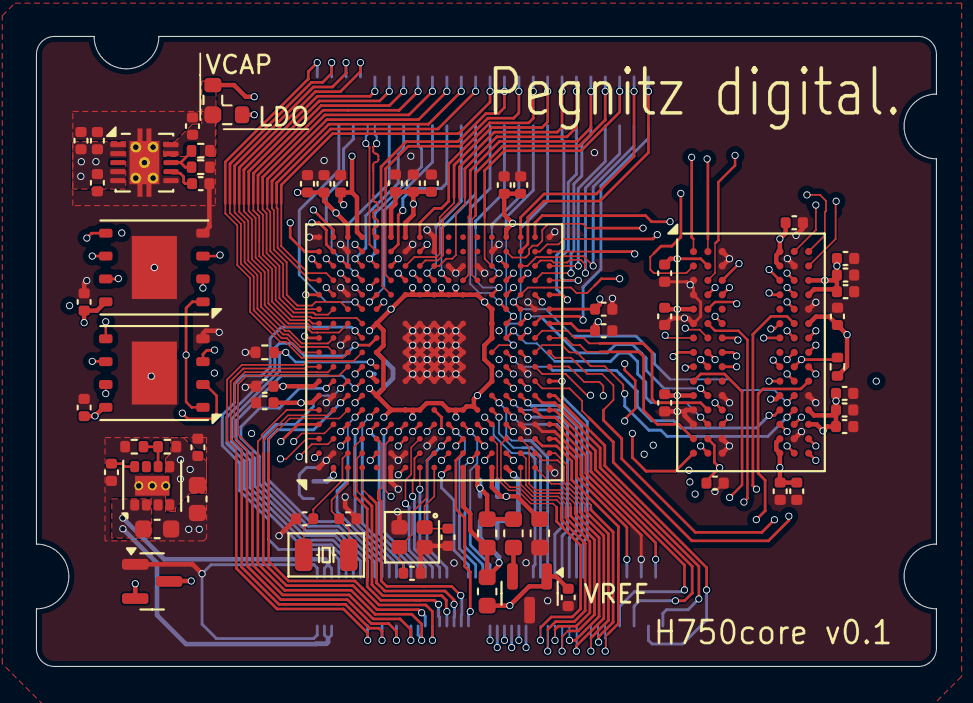
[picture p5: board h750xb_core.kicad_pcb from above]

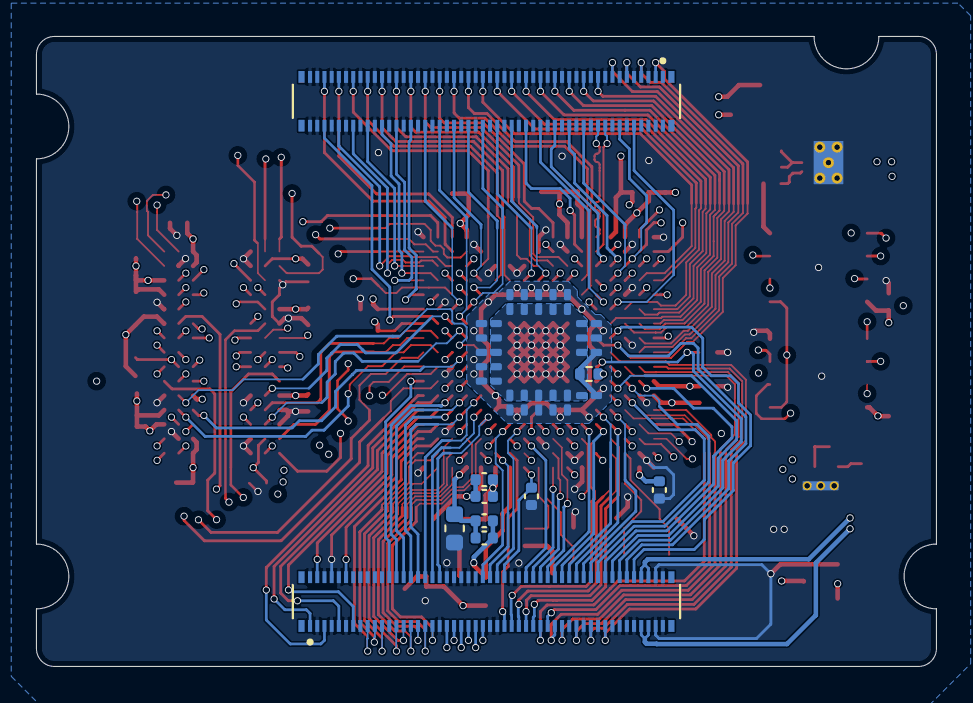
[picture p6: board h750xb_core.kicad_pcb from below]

Board: 6 copper layers, 50.0 x 35.0 mm, 93 parts (29 on the bottom side), 190 nets.

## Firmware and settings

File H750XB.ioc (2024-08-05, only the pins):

Mcu.UserName=STM32H750XBHx
PA3.Signal=USB_OTG_HS_ULPI_D0
PA5.Signal=USB_OTG_HS_ULPI_CK
PB0.Signal=USB_OTG_HS_ULPI_D1
PB1.Signal=USB_OTG_HS_ULPI_D2
PB10.Signal=USB_OTG_HS_ULPI_D3
PB11.Signal=USB_OTG_HS_ULPI_D4
PB12.Signal=USB_OTG_HS_ULPI_D5
PB13.Signal=USB_OTG_HS_ULPI_D6
PB5.Signal=USB_OTG_HS_ULPI_D7
PC0.Signal=USB_OTG_HS_ULPI_STP
PC10.Signal=QUADSPI_BK1_IO1
PC11.Signal=QUADSPI_BK2_NCS
PC2.Signal=FMC_SDNE0
PC3.Signal=FMC_SDCKE0
PC9.Signal=QUADSPI_BK1_IO0
PD0.Signal=FMC_D2_DA2
PD1.Signal=FMC_D3_DA3
PD10.Signal=FMC_D15_DA15
PD14.Signal=FMC_D0_DA0
PD15.Signal=FMC_D1_DA1
PD8.Signal=FMC_D13_DA13
PD9.Signal=FMC_D14_DA14
PE0.Signal=FMC_NBL0
PE1.Signal=FMC_NBL1
PE10.Signal=FMC_D7_DA7
PE11.Signal=FMC_D8_DA8
PE12.Signal=FMC_D9_DA9
PE13.Signal=FMC_D10_DA10
PE14.Signal=FMC_D11_DA11
PE15.Signal=FMC_D12_DA12
PE7.Signal=FMC_D4_DA4
PE8.Signal=FMC_D5_DA5
PE9.Signal=FMC_D6_DA6
PF0.Signal=FMC_A0
PF1.Signal=FMC_A1
PF10.Signal=QUADSPI_CLK
PF11.Signal=FMC_SDNRAS
PF12.Signal=FMC_A6
PF13.Signal=FMC_A7
PF14.Signal=FMC_A8
PF15.Signal=FMC_A9
PF2.Signal=FMC_A2
PF3.Signal=FMC_A3
PF4.Signal=FMC_A4
PF5.Signal=FMC_A5
PF6.Signal=QUADSPI_BK1_IO3
PF7.Signal=QUADSPI_BK1_IO2
PG0.Signal=FMC_A10
PG1.Signal=FMC_A11
PG14.Signal=QUADSPI_BK2_IO3
PG15.Signal=FMC_SDNCAS
PG2.Signal=FMC_A12
PG4.Signal=FMC_A14_BA0
PG5.Signal=FMC_A15_BA1
PG8.Signal=FMC_SDCLK
PG9.Signal=QUADSPI_BK2_IO2
PH10.Signal=FMC_D18
PH11.Signal=FMC_D19
PH12.Signal=FMC_D20
PH13.Signal=FMC_D21
PH14.Signal=FMC_D22
PH15.Signal=FMC_D23
PH2.Signal=QUADSPI_BK2_IO0
PH3.Signal=QUADSPI_BK2_IO1
PH4.Signal=USB_OTG_HS_ULPI_NXT
PH5.Signal=FMC_SDNWE
PH8.Signal=FMC_D16
PH9.Signal=FMC_D17
PI0.Signal=FMC_D24
PI1.Signal=FMC_D25
PI10.Signal=FMC_D31
PI11.Signal=USB_OTG_HS_ULPI_DIR
PI2.Signal=FMC_D26
PI3.Signal=FMC_D27
PI4.Signal=FMC_NBL2
PI5.Signal=FMC_NBL3
PI6.Signal=FMC_D28
PI7.Signal=FMC_D29
PI9.Signal=FMC_D30

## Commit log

2024-06-16 TPS82130 fb
    [power.kicad_sch]
2024-07-01 更新物料 删除16bit sdram*2 改为32bit sdram*1
    [h750xb_core.kicad_pcb, mcu.kicad_sch]
2024-07-06 MCU部分扇出，SDRAM走线ing
    [h750xb_core.kicad_pcb, mcu.kicad_sch, power.kicad_sch]
2024-07-08 绕走SDRAM走线。。因复杂度太高，放弃做等长 目前差最后几根数据线，可视情况交换线序
    [h750xb_core.kicad_pcb, mcu.kicad_sch]
2024-07-10 完成了SDRAM和QSPI的走线，QSPI做了网络等长匹配（两根复用线未连接以用于准确计算线长）
    [h750xb_core.kicad_pcb, h750xb_core.kicad_sch, mcu.kicad_sch]
2024-07-11 铺铜，增加BTB
    [DF40C-100DP-0.4V_51_.step, h750xb_core.kicad_pcb, h750xb_core.kicad_sch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]
2024-07-11 为什么又不能用git！！！！！！！
    [h750xb_core.kicad_sch, mcu.kicad_sch]
2024-07-17 更新原理图网络和PCB部分IO走线
    [h750xb_core.kicad_pcb, h750xb_core.kicad_sch, mcu.kicad_sch]
2024-07-18 完工0-0
    [h750xb_core.kicad_pcb, h750xb_core.kicad_sch, mcu.kicad_sch]
2024-07-19 导出gerber
    [h750xb_core-B_Mask.gbr, h750xb_core-B_Paste.gbr, h750xb_core-B_Silkscreen.gbr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]
2024-08-05 失能部分不使用的外设
